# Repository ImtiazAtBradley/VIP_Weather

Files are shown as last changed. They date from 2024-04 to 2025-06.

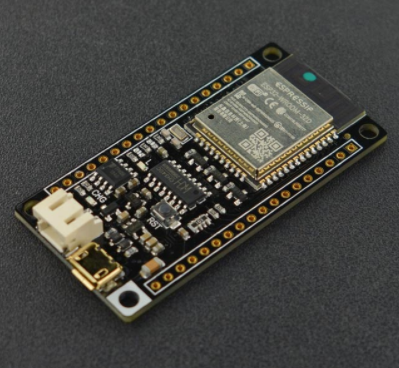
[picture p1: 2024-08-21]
images/esp32.png

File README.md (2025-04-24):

# Bradley Weather Station - Overview

The source code for the Bradley Weather Station website/api/firmware/broker. The data produced by the station is available at [weather.jacobsimeone.net](https://weather.jacobsimeone.net). 

- [Hardware Design on OnShape](https://cad.onshape.com/documents/38c15368c41f2224b0adceca/w/e0d05cb6b75a73d47582f798/e/6f88f03cdb676fd77e352c81)
- [Documentation](https://litemage.github.io/vip-weather-docs/)
- [Documentation GitHub (separate from this repository)](https://github.com/Litemage/vip-weather-docs)

# Contributors

**Spring 2024**
- Jacob S. 
- Kyle K.
- Christopher H.
- Emily A.
- Owen J.
- Samantha P.
- Dr. Imtiaz - **Advisor**

**Fall 2024**
- Ryuto N.
- Freddie M.
- Logan V.
- Grace T.

**Spring 2025**
- Matthew V.
- Riley P.

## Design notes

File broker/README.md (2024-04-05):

# Overview

The broker program is designed to go along with the weather station website, and the various devices. The broker queries a radio attached to a device on a serial port, and then parses & passes received messages on to a redis database, as indicated by the user. 

NOTE: This software will only work with POSIX compliant systems (linux/MacOs). Only tested for Ubuntu

# Requirements

- [ ] Receives and parses messages received through serial port via radio. (Abstract through port api)
- [ ] Publishes received data to redis database
- [ ] User can input redis server destination
- [ ] Logs failures to stdout/stderr

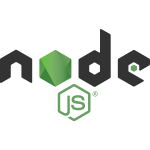
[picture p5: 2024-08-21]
images/nodejs.png

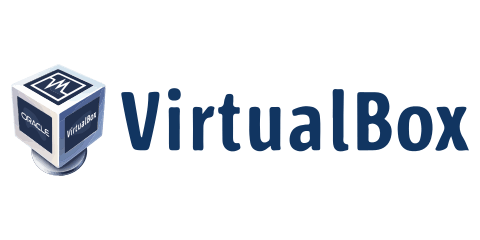
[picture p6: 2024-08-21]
images/virtualbox.png

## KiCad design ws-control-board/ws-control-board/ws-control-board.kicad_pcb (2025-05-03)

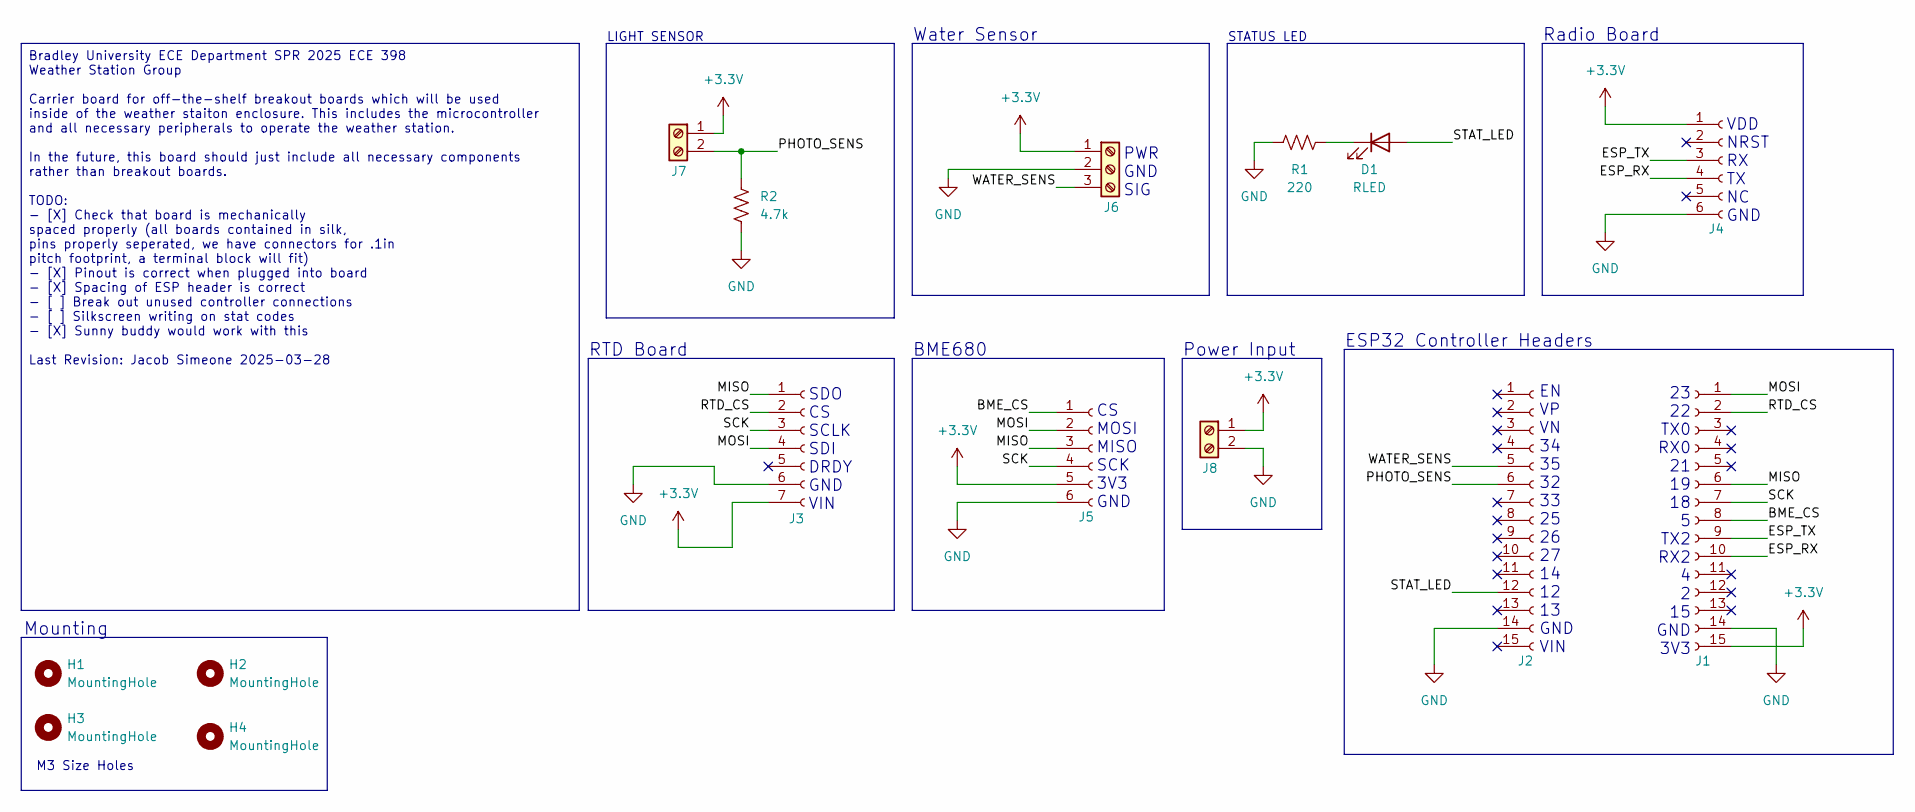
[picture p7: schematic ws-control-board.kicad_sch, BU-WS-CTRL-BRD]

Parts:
D1: RLED; LED_D5.0mm
H1, H2, H3, H4: MountingHole; MountingHole_3.2mm_M3
J1, J2: Conn_01x15_Socket; PinSocket_1x15_P2.54mm_Vertical
J3: Conn_01x07_Socket; PinSocket_1x07_P2.54mm_Vertical
J4, J5: Conn_01x06_Socket; PinSocket_1x06_P2.54mm_Vertical
J6: Screw_Terminal_01x03; PinHeader_1x03_P2.54mm_Vertical
J7, J8: Screw_Terminal_01x02; PinHeader_1x02_P2.54mm_Vertical
R1: 220; R_Axial_DIN0207_L6.3mm_D2.5mm_P10.16mm_Horizontal
R2: 4.7k; R_Axial_DIN0207_L6.3mm_D2.5mm_P10.16mm_Horizontal

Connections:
+3.3V: J1.15, J3.7, J4.1, J5.5, J6.1, J7.1, J8.1
/BME_CS: J1.8, J5.1
/ESP_RX: J1.10, J4.4
/ESP_TX: J1.9, J4.3
/MISO: J1.6, J3.1, J5.3
/MOSI: J1.1, J3.4, J5.2
/PHOTO_SENS: J2.6, J7.2, R2.2
/RTD_CS: J1.2, J3.2
/SCK: J1.7, J3.3, J5.4
/STAT_LED: D1.2 (A), J2.12
/WATER_SENS: J2.5, J6.3
GND: J1.14, J2.14, J3.6, J4.6, J5.6, J6.2, J8.2, R1.1, R2.1
unnamed: D1.1 (K), R1.2

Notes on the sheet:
Radio Board
CS MOSI MISO SCK 3V3 GND
PWR GND SIG
SDO CS SCLK SDI DRDY GND VIN
M3 Size Holes
RTD Board
Mounting
STATUS LED
VDD NRST RX TX NC GND
23 22 TX0 RX0 21 19 18 5 TX2 RX2 4 2 15 GND 3V3
BME680
EN VP VN 34 35 32 33 25 26 27 14 12 13 GND VIN
LIGHT SENSOR
Power Input
ESP32 Controller Headers
Water Sensor
Bradley University ECE Department SPR 2025 ECE 398 Weather Station Group Carrier board for off-the-shelf breakout boards which will be used inside of the weather staiton enclosure. This includes the microcontroller and all necessary peripherals to operate the weather station. In the future, this bo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

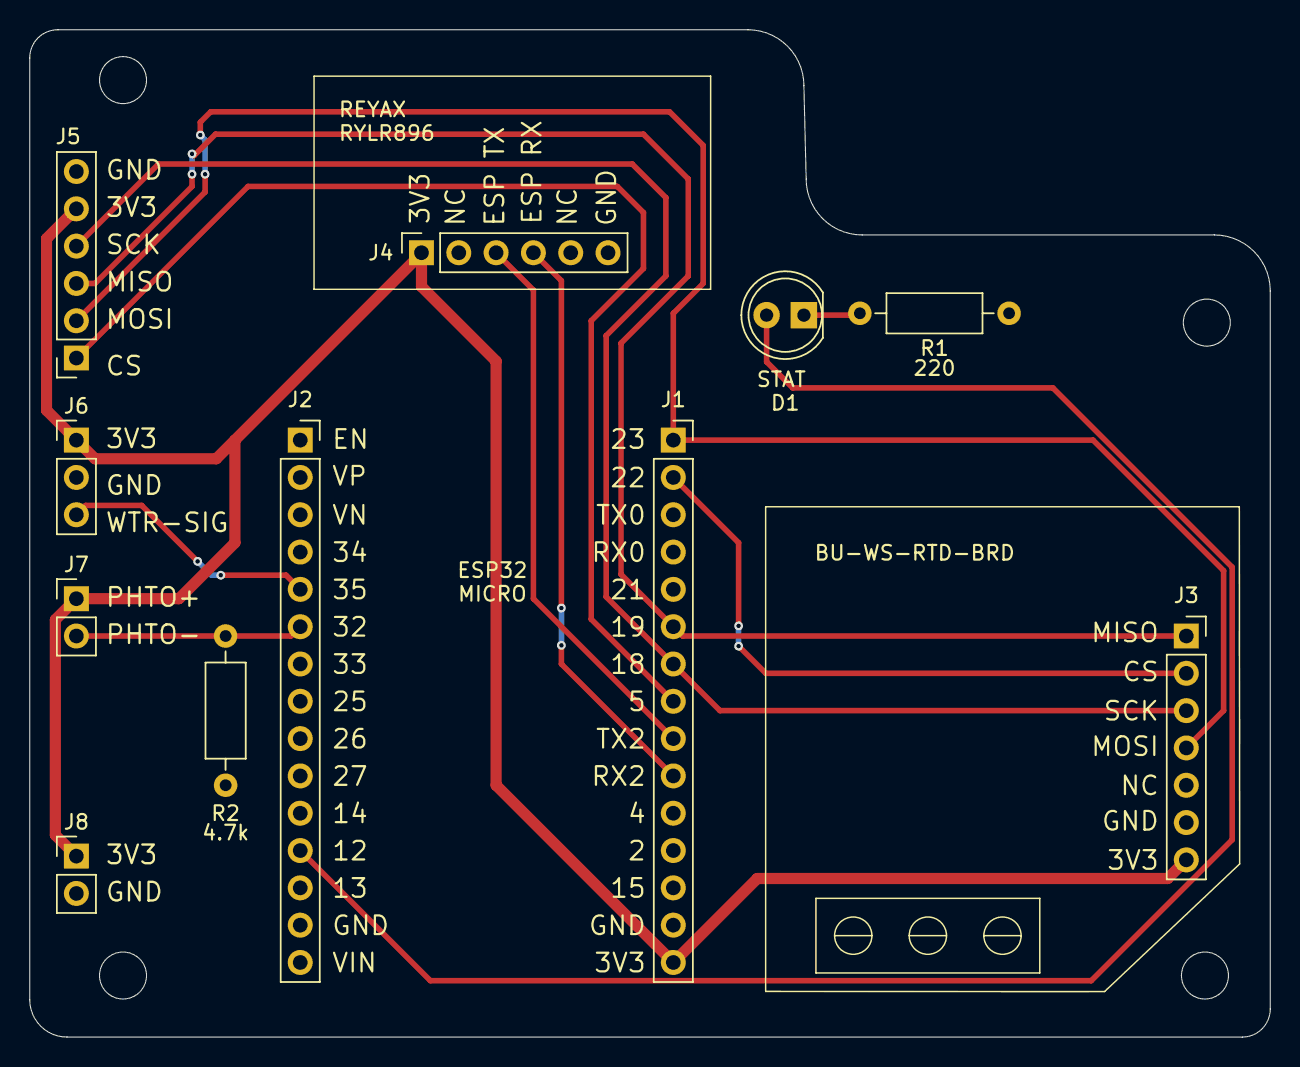
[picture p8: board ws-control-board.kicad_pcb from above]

Board: 2 copper layers, 84.5 x 68.6 mm, 15 parts (0 on the bottom side), 13 nets.

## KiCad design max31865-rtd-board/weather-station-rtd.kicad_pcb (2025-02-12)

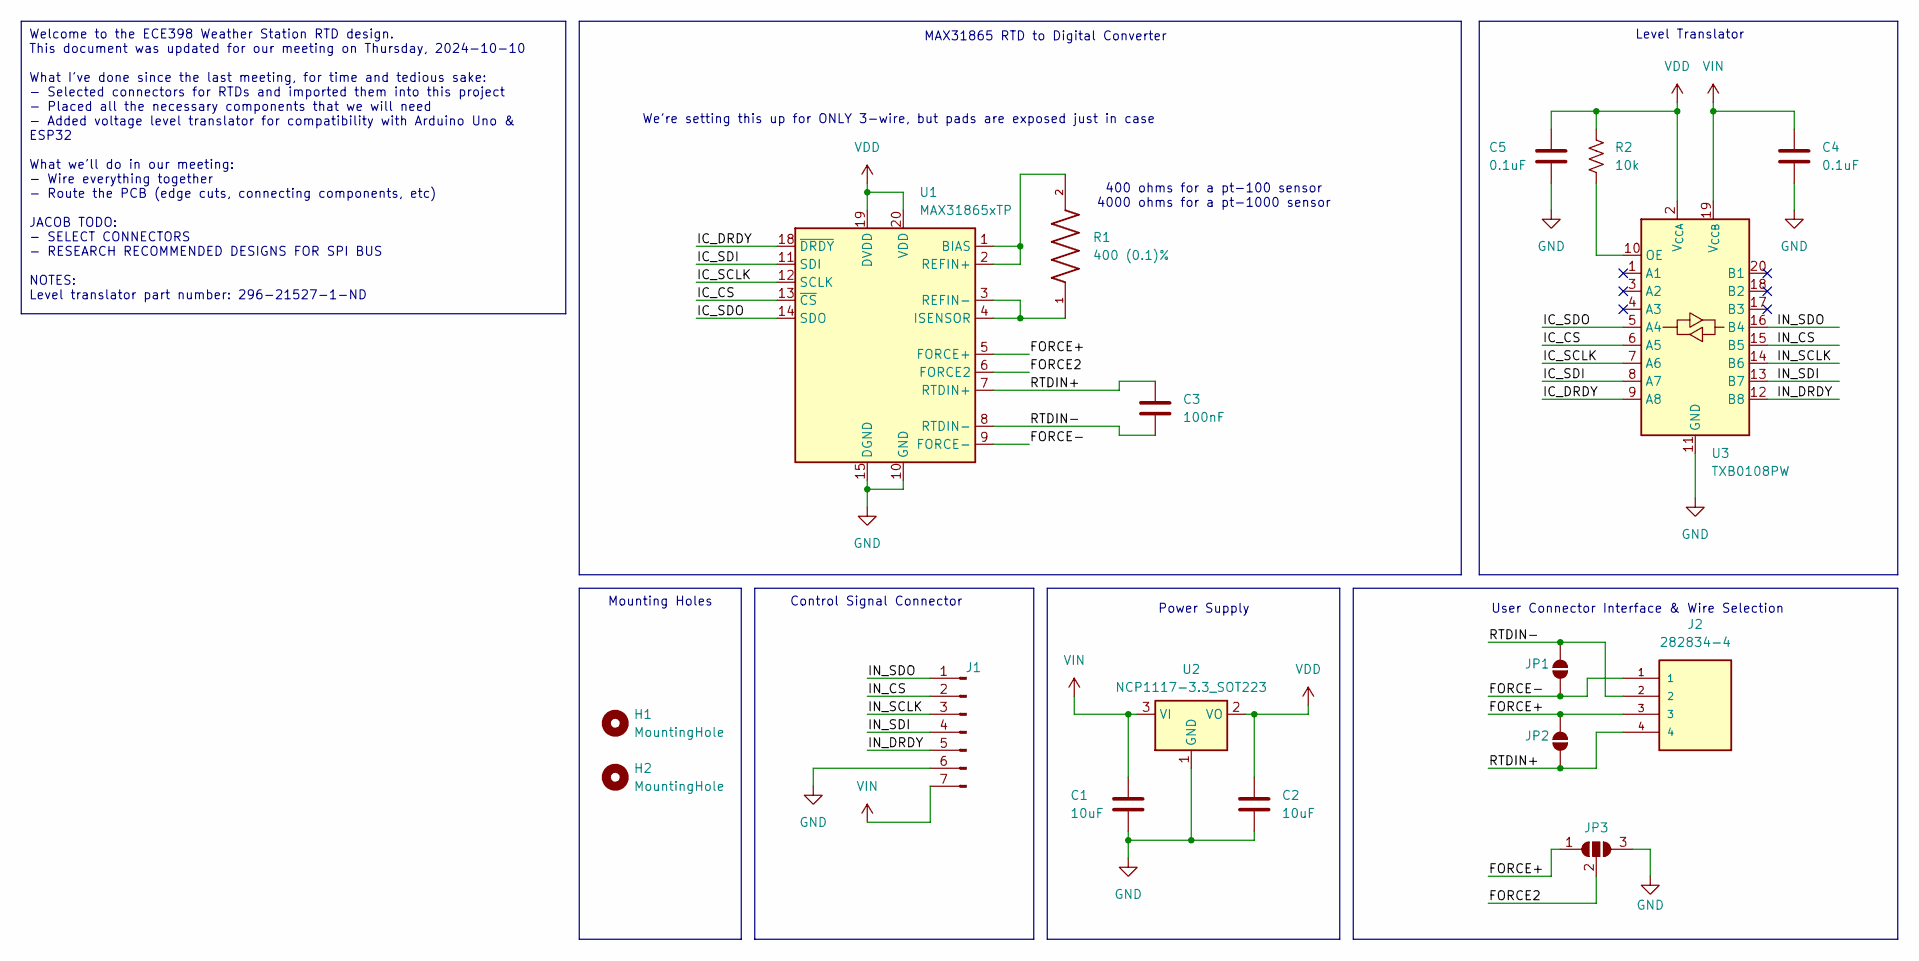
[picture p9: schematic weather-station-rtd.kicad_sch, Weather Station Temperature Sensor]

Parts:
C1, C2: 10uF; C_0805_2012Metric
C3: 100nF; C_0805_2012Metric
C4, C5: 0.1uF; C_0805_2012Metric
H1, H2: MountingHole; MountingHole_3.2mm_M3
J1: Conn_01x05_Pin; PinHeader_1x07_P2.54mm_Vertical
J2: 282834-4; TE_282834-4; PARTREV D
JP1, JP2: SolderJumper-2_P1.3mm_Open_TrianglePad1.0x1.5mm
JP3: SolderJumper-3_P1.3mm_Open_RoundedPad1.0x1.5mm_NumberLabels
R1: 400 (0.1)%; RESC3116X65N
R2: 10k; C_0805_2012Metric
U1: MAX31865xTP; TQFN-20-1EP_5x5mm_P0.65mm_EP3.25x3.25mm
U2: NCP1117-3.3_SOT223; SOT-223-3_TabPin2
U3: TXB0108PW; TSSOP-20_4.4x6.5mm_P0.65mm

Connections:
/FORCE2: JP3.2 (C), U1.6 (FORCE2)
/FORCE+: J2.3, JP2.2 (B), JP3.1 (A), U1.5 (FORCE+)
/FORCE-: J2.1, JP1.1 (A), U1.9 (FORCE-)
/IC_CS: U1.13 (~CS), U3.6 (A5)
/IC_DRDY: U1.18 (~DRDY), U3.9 (A8)
/IC_SCLK: U1.12 (SCLK), U3.7 (A6)
/IC_SDI: U1.11 (SDI), U3.8 (A7)
/IC_SDO: U1.14 (SDO), U3.5 (A4)
/IN_CS: J1.2, U3.15 (B5)
/IN_DRDY: J1.5, U3.12 (B8)
/IN_SCLK: J1.3, U3.14 (B6)
/IN_SDI: J1.4, U3.13 (B7)
/IN_SDO: J1.1, U3.16 (B4)
/RTDIN+: C3.1, J2.4, JP2.1 (A), U1.7 (RTDIN+)
/RTDIN-: C3.2, J2.2, JP1.2 (B), U1.8 (RTDIN-)
GND: C1.2, C2.2, C4.2, C5.2, J1.6, JP3.3 (B), U1.10 (GND), U1.15 (DGND), U1.16 (GND), U1.21 (GND), U2.1 (GND), U3.11 (GND)
unnamed: R1.2, U1.1 (BIAS), U1.2 (REFIN+)
unnamed: R1.1, U1.3 (REFIN-), U1.4 (ISENSOR)
unnamed: R2.2, U3.10 (OE)
VDD: C2.1, C5.1, R2.1, U1.19 (DVDD), U1.20 (VDD), U2.2 (VO), U3.2 (V_{CCA})
VIN: C1.1, C4.1, J1.7, U2.3 (VI), U3.19 (V_{CCB})

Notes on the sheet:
Welcome to the ECE398 Weather Station RTD design. This document was updated for our meeting on Thursday, 2024-10-10 What I've done since the last meeting, for time and tedious sake: - Selected connectors for RTDs and imported them into this project - Placed all the necessary components that we will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
400 ohms for a pt-100 sensor 4000 ohms for a pt-1000 sensor
MAX31865 RTD to Digital Converter
Power Supply
Control Signal Connector
Mounting Holes
Level Translator
We're setting this up for ONLY 3-wire, but pads are exposed just in case
User Connector Interface & Wire Selection

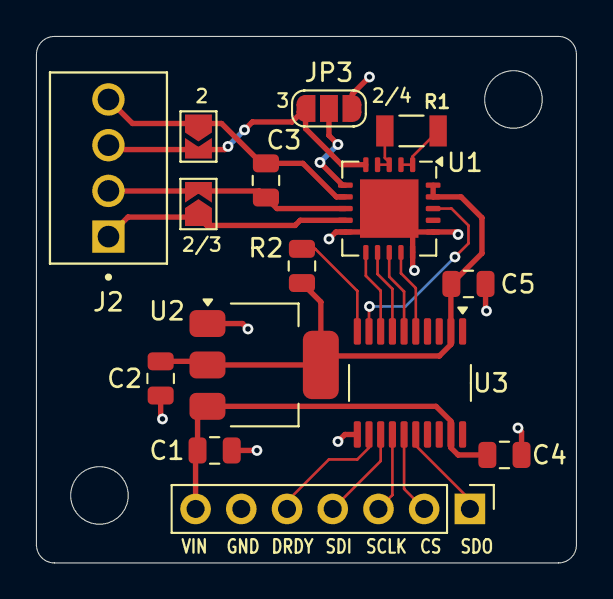
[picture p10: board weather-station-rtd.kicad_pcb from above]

Board: 2 copper layers, 30.0 x 29.2 mm, 17 parts (0 on the bottom side), 21 nets.

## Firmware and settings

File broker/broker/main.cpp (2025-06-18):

#include <cerrno>
#include <cstring>
#include <algorithm>
#include <iostream>
#include <fstream>
#include <regex>
#include <sys/stat.h>
#include <cstdlib>

#include "utils.h"
#include "broker.h"
#include "constants.h"
#include "wslogger.h"

#define LOG_FILE      "/var/log/bu-weather/broker.log" // path to log file
#define LOG_FILE_SIZE 1024 * 10                        // Size of each log file
#define LOG_FILE_NUM  5                                // Number of log files

// ============================ MAIN PROGRAM ============================

static void
FailOut()
{
   std::cout << "INVALID INPUT. SEE USAGE:\n\n";
   Broker::help();
   exit(EXIT_FAILURE);
}

int
main(int argc, char *argv[])
{
   if (argv[1] == nullptr)
   {
      FailOut();
   }

   // Try to get URL from command line arguments
   if (argv[2] == nullptr)
   {
      std::cerr << "MISSING: You must provide an API URL\n";
      FailOut();
   }

   std::string url = argv[2]; // Kind of trusting here this was a valid URL

   // Try to get the API key from the provided file

   if (argv[3] == nullptr)
   {
      std::cerr << "MISSING: You must provide a key file" << std::endl;
      FailOut();
   }

   std::string keyFilePath = argv[3];

   std::optional<std::string> key = GetFileContent(keyFilePath);

   if (!key)
   {
      std::cerr << "Invalid key file path\n";
      FailOut();
   }

   // Hacky, but works for our purposes - check for ascii only in the future too
   auto check_whitespace = [](char x) { return x == ' ' || x == '\n' || x == '\r' || x == '\t'; };
   bool contains_whitespace =
       std::find_if(key.value().begin(), key.value().end(), check_whitespace) != key.value().end();

   if (key == "")
   {
      std::cerr << "Key file is empty" << std::endl;
      FailOut();
   }
   else if (contains_whitespace)
   {
      std::cerr << "Key file contains invalid whitespace, did you accidentally leave some?" << std::endl;
      std::cerr << "Got api key: \"" << key.value() << "\"\n";
      FailOut();
   }

   // Check if log file directory exists
   if (!std::filesystem::is_directory(std::filesystem::path(LOG_FILE).parent_path()))
   {
      if (mkdir(LOG_FILE, 0755) != 0)
      {
         std::cerr << "Failed to initialize log file containing directory at: " << LOG_FILE << "\nCheck that this program can create that directory";
      }
   }

   // Run broker scheduler every 1000ms
   Broker broker = Broker(std::chrono::milliseconds(1000),
                          std::string(argv[1]),
                          url,
                          key.value(),
                          LOG_FILE,
                          LOG_FILE_SIZE,
                          LOG_FILE_NUM);

   // Print program header
   Broker::printProgramHeader();

   // SETUP SERIAL FILE

   if (!broker.serialFileGood() || !broker.setupSerialPort())
   {
      std::cerr << "INVALID FILE INPUT. SEE USAGE:\n\n";
      Broker::help();
      exit(EXIT_FAILURE);
   }

   std::cout << "[DEBUG] Initialized serial port\n";

   // HACK: Write to radio to set it up
   broker.writeToPort("AT+ADDRESS=1\r\n");

   broker.m_wsLog.Info("Starting broker");

   while (1)
   {
      broker.runScheduler();
   }
}

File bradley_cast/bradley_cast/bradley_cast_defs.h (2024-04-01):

/**
 * BRADLEY CAST PROTOCOL
 *
 * This header implementes the BradleyCast protocol for the weather station's
 * link between itself and a server running broker software.
 *
 * AUTHORS: ECE398-23SPR Weather Station Group
 *
 * CONTACT: jsimeone@mail.bradley.edu
 */

#ifndef __BRADLEY_CAST_DEFS_H__
#define __BRADLEY_CAST_DEFS_H__

#include <stdint.h>

/* ================================================== */
/*                   UNITS - SCALE                    */
/* ================================================== */

#define TEMPERATURE_SCALE_C (100)
#define HUMID_SCALE_PERCENT (100)
#define PRESSURE_SCALE_KPA  (100)

/* ================================================== */
/*                MESSAGE LEN (BTYES)                 */
/* ================================================== */

#define STATION_ID_LEN      (4)
#define MSG_ID_LEN          (2)
#define TEMP_LEN            (2)
#define HUMID_LEN           (2)
#define PRESSURE_LEN        (2)
#define RCSG_LEN            (1)

#define MSG_HEAD_LEN (STATION_ID_LEN + MSG_ID_LEN)

/* ================================================== */
/*                    ENUMERATIONS                    */
/* ================================================== */

typedef enum
{
   BC_SUNNY = 0,
   BC_CLOUDY = 1,
   BC_GLOOMY = 2
} bc_scg_t;

typedef enum
{
   MSG_ENV_ID = 0x0010,

   MSG_ID_INVALID,
} bc_msg_id_t;

/* ================================================== */
/*                       MESSAGES                     */
/* ================================================== */

/* MESSAGE STRUCTURE */

typedef struct
{
   uint32_t station_id;
   uint16_t msg_id;
   void *msg_paylod;
   size_t payload_len;
} bc_msg_t;

/* ENVIRONMENTAL DATA MESSAGE */

#define MSG_ENV_LEN         (7) /* Payload Length */
#define MSG_ENV_BITMSK_RAIN (0x01)
// Sunny/Cloudy/Gloomy
#define MSG_ENV_BITMSK_SCG  (0x06)

// Data that will be parsed into message
typedef struct
{
   float temp_c;
   float humid_prcnt;
   float press_kpa;
   // Rainy, sunny, cloudy, gloomy (see protocol documentation)
   uint8_t is_rainy;
   bc_scg_t light_level;
} bc_env_data_t;

#endif // __BRADLEY_CAST_DEFS_H__

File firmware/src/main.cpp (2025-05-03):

/**
 * @file main.cpp
 * @brief VIP Project weather station source
 * 
 */
#include <Arduino.h>
#include <weather_station.h>

// #define DEBUG

/* ========================================================================== */
/*                                MAIN PROGRAM                                */
/* ========================================================================== */

#ifdef DEBUG
static long lastDebug = LONG_MAX;
#endif

static long lastTransmit = LONG_MAX;

void
setup() {
    Serial.begin(115200);

    Serial.println("BOOTING...");

    delay(500);

    // ws_init also turns on status LED
    if (!ws_init()) {
        // Blink a couple times to notify user
        for (int i = 0; i < 3; ++i) {
            ws_set_status_led(false);
            delay(500);
            ws_set_status_led(true);
            delay(500);
        }

        Serial.println("BOOT RTRY");
        // Wait before soft restart so user can see above message
        delay(1000);
        // Perform a soft restart
        ws_reset_controller();
    }

    Serial.println("BOOT OK");

    // Turn off status LED after boot
    // delay to make it clear this was the boot exiting
    ws_set_status_led(false);
    delay(1000);
}

void
loop() {
    static weather_data_t wd = {0};
    float temp_c = 0.0f, humidity = 0.0f, pres_kpa = 0.0f, gas_kohms = 0.0f, an_wet = 0.0f, an_light = 0.0f;

    temp_c = ws_get_temperature();
    an_wet = ws_get_analog_water();
    humidity = ws_get_humidity();
    pres_kpa = ws_get_pressure();
    gas_kohms = ws_get_gas_sensor();
    an_light = ws_get_analog_light();

    wd.temp_c = temp_c;
    wd.wet_analog = an_wet;
    wd.humid = humidity;
    wd.pres_kpa = pres_kpa;
    wd.gas_kohms = gas_kohms;
    wd.light_analog = an_light;

#ifdef DEBUG
    if (millis() - lastDebug > 1000) {
        // Blink to indicate it's not dead
        ws_set_status_led(true);
        delay(20);
        ws_set_status_led(false);
        // Print out some debug stuff
        Serial.println("[DEBUG] CURRENT VALUES: ");
        Serial.print("Water Level..........");
        Serial.print(wd.wet_analog);
        Serial.print("\n");
        Serial.print("Light Level..........");
        Serial.print(wd.light_analog);
        Serial.print("\n");
        Serial.print("Temperature..........");
        Serial.print(wd.temp_c);
        Serial.print("\n");
        Serial.print("Pressure Level.......");
        Serial.print(wd.pres_kpa);
        Serial.print("\n");
        Serial.print("Humidity Level.......");
        Serial.print(wd.humid);
        Serial.print("\n");
        Serial.print("Gas Sensor...........");
        Serial.print(wd.gas_kohms);
        Serial.print("\n");

        Serial.print("........................................\n");

        lastDebug = millis();
    }
#endif

    if (millis() - lastTransmit > TX_INTERVAL_MS) {

        String temp_c, humid, pres_kpa, wet, light, gas_kohms;
        temp_c = String(wd.temp_c);
        humid = String(wd.humid);
        pres_kpa = String(wd.pres_kpa);
        gas_kohms = String(wd.gas_kohms);
        wet = String(wd.wet_analog);
        light = String(wd.light_analog);
        String d = "T" + temp_c + "|H" + humid + "|P" + pres_kpa + "|G" + gas_kohms + "|R" + wet + "|L" + light;

#ifdef DEBUG
        Serial.print("Would transmit data: ");
        Serial.println(d);
#else
        ws_tx_data(2, d);
#endif

        ws_set_status_led(true);
        delay(30);
        ws_set_status_led(false);

        lastTransmit = millis();
    }

    delay(250);
}

/* ========================================================================== */
/*                        PRIVATE FUNCTION DEFINITIONS                        */
/* ========================================================================== */

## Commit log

2024-03-01 Remove Bootstrap - Add Information
    - Bootstrap is too big to merit use on ESP32
    - Add own styling + Information
    [weather_station.cpp]
2024-03-01 Fix Spelling
    I forgot to turn on my spell check...
    [weather_station.cpp]
2024-03-01 Fix Bugs
    - Fix: Samantha's initial
    - Light sensor threshold
    - Weird character on page
    - Redirection on windows computers
    [main.cpp, weather_station.cpp]
2024-03-01 Fix table for mobile
    [weather_station.cpp]
2024-03-04 Increase Power
2024-04-11 Fix double free. DB connect
    [main.cpp, weather_station.cpp]
2024-04-13 Prototype Webpage
2024-04-14 Broker opens serial port
    [main.cpp]
2024-04-14 Broker parses incoming data
    [main.cpp]
2024-04-15 Prototype API
2024-04-24 Ready for demo
    - Weather station tx interval at 30 seconds
    - LED lights up after transmission
    - Added configuration files
2024-04-25 More demo updates
    Fix: Memory leak
    Tweak: Change to 5 second tx time for firmware
    Fix: Update Next.js
    [main.cpp]
2024-10-28 WIP broker change to API
    [main.cpp]
2024-11-08 website + api + broker improvements
    - Broker now posts data to API successfully
    - Added a "who build this?" section on the website
    - API data now has timestamp instead of sample
    - Broker checks for invalid API key file
    [main.cpp]
2024-11-14 Update Firmware
    - Boot logic updated. Much more clear
    - Soft reset on boot fail
    [main.cpp, weather_station.cpp]
2025-01-25 Revert "Merge pull request #8 from deviousgoose/dev/bem680"
    This reverts commit c0659df68e0beccd2334d530cdb0eb8e3aa03ed6, reversing
    changes made to 68203e5bd0544a41c5090b4a73ce95e302e5f272.
    [main.cpp, weather_station.cpp]
2025-01-25 Update With Currently Deployed Services
2025-02-11 Reapply "Merge pull request #8 from deviousgoose/dev/bem680"
    This reverts commit a11d2372f45b25cb712d9df007ce1cde29c17d88.
    [main.cpp, weather_station.cpp]
2025-02-12 Add rtd board to git
    [weather-station-rtd-B_Courtyard.gbr, weather-station-rtd-B_Cu.gbr, weather-station-rtd-B_Mask.gbr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]
2025-02-25 Radio debugging, Data Changes
    - Change to sending analog data values for light and water
    - Remove radio reset pin
2025-03-02 Prototype Broker Code
2025-03-13 Switch to measuring temp with RTD.
    MUST VERIFY AND INPUT CS PIN
2025-03-29 Add a control board to mount inside the station
    [ws-control-board-B_Cu.gbr, ws-control-board-B_Mask.gbr, ws-control-board-B_Paste.gbr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]
2025-03-30 Fix board bugs
    [ws-control-board-B_Cu.gbr, ws-control-board-B_Mask.gbr, ws-control-board-B_Paste.gbr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]
2025-04-04 Update schematic todo
    [ws-control-board.kicad_sch]
2025-04-24 Update README.md
    Added Spring 2025
2025-05-08 Fixed compile errors. Added spdlog to cmake
    [main.cpp]
